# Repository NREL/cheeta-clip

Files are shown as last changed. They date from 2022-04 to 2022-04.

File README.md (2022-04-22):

# Cheeta clip
The Cheeta clip holds flat objects onto a rack. It is made for deploying small solar photovoltaic (PV) modules outdoors.

Cheeta clips in use

## Features
- Very fast, tool-less attachment to a rack
- Very fast, tool-less installation and removal of samples
- Fully 3D-printable
- Uses about USD 0.10 worth of material per clip

## Usage
Position rails according to the *rail slot spacing* in the version table below.

Set the springs inside of each clip.

https://user-images.githubusercontent.com/416769/164803713-2e9b144f-7e71-470b-b48f-9a773c60ec67.mov

Install at least two upper clips in the upper rail using a quarter-twist.

https://user-images.githubusercontent.com/416769/164803848-d7899543-1e59-406c-ba7a-e5604aac1d8c.mov

Install at least two lower clips in the lower rail using a quarter-twist.

https://user-images.githubusercontent.com/416769/164803891-bc1108ad-c702-4ae0-a931-0f3074bd0d42.mov

Insert the sample into the upper clips, then tilt the sample and slide it into the lower clips.

https://user-images.githubusercontent.com/416769/164804314-834fb0a4-f364-4763-a8cf-b462d6e22f0f.mov

## Versions
version | rail type | sample thickness range | clip overlap | rail slot spacing
--- | --- | --- | --- | ---
A | 80-20 15 series | 3 mm–8 mm | 5 mm | sample height − 23 mm

## Printing recommendations
### Slicing and printing
We make Cheeta clips using ordinary FFF 3D printers. We use a 0.6-mm nozzle. We slice with 4 perimeters to strengthen the inside corner fillet and use 15% infill.

### Material
We use white PETG, which should last at least several months outdoors while holding adequate spring tension.

PLA is not recommended because it creeps at room temperature and loses spring tension overnight.

## Contact
If you have tried this clip, or if you have a comment or suggestion, please contact the author, Tim Silverman <timothy.silverman@nrel.gov>.

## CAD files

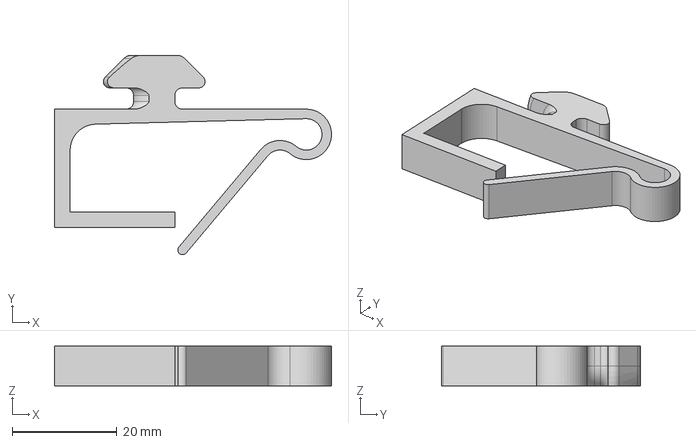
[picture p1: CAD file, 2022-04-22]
3D files/cheeta clip A upper.step
52.9 x 38.1 x 7.62 mm

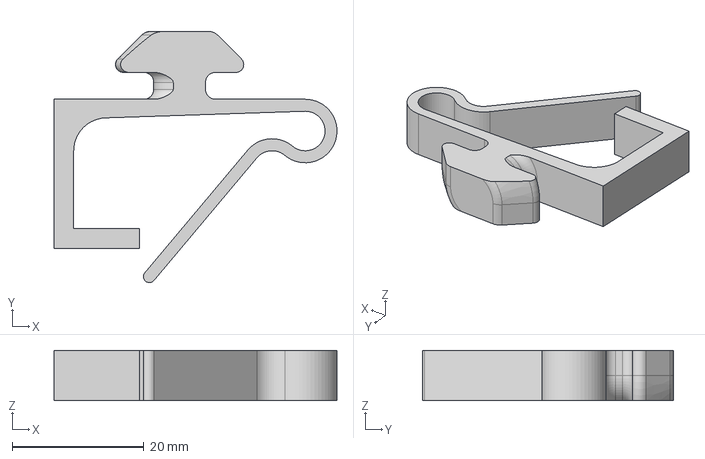
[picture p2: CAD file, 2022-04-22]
3D files/cheeta clip A lower.step
42.9 x 38.1 x 7.62 mm

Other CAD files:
3D files/cheeta clip A lower.stl
3D files/cheeta clip A upper.stl
